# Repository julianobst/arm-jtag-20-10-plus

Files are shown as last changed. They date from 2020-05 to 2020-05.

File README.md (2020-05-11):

# arm-jtag-20-10-plus
KiCad project for ARM Cortex-M JTAG Adapter with 20, 10 and 6 pin target header

The adaptor can be used by a debug probe with a standard [ARM JTAG 20](http://infocenter.arm.com/help/index.jsp?topic=/com.arm.doc.dui0499d/BEHEIHCE.html) connector with 2.54 mm pitch and 2x10 pins. Like SEGGER J-Link, Olimex ARM-USB-TINY, STLINK-V3SET etc.

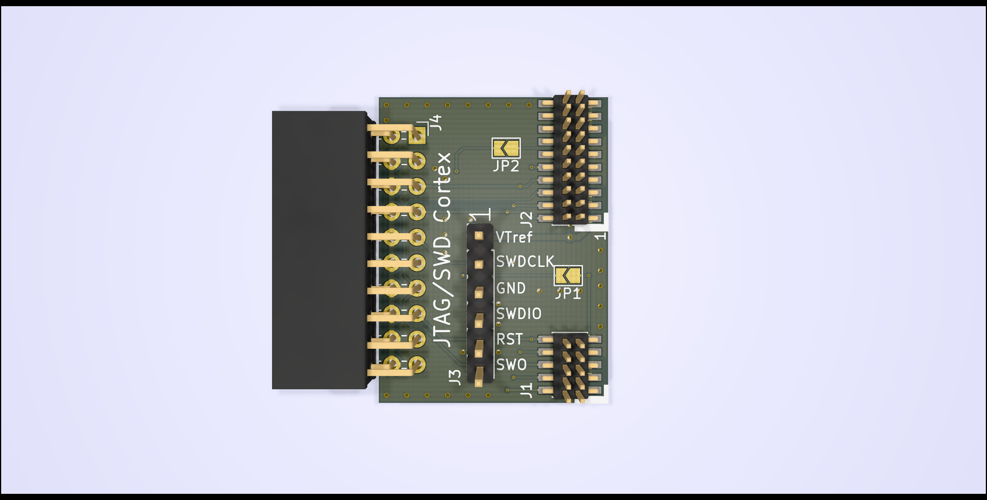
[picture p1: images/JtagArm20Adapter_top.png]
Adaptor top view

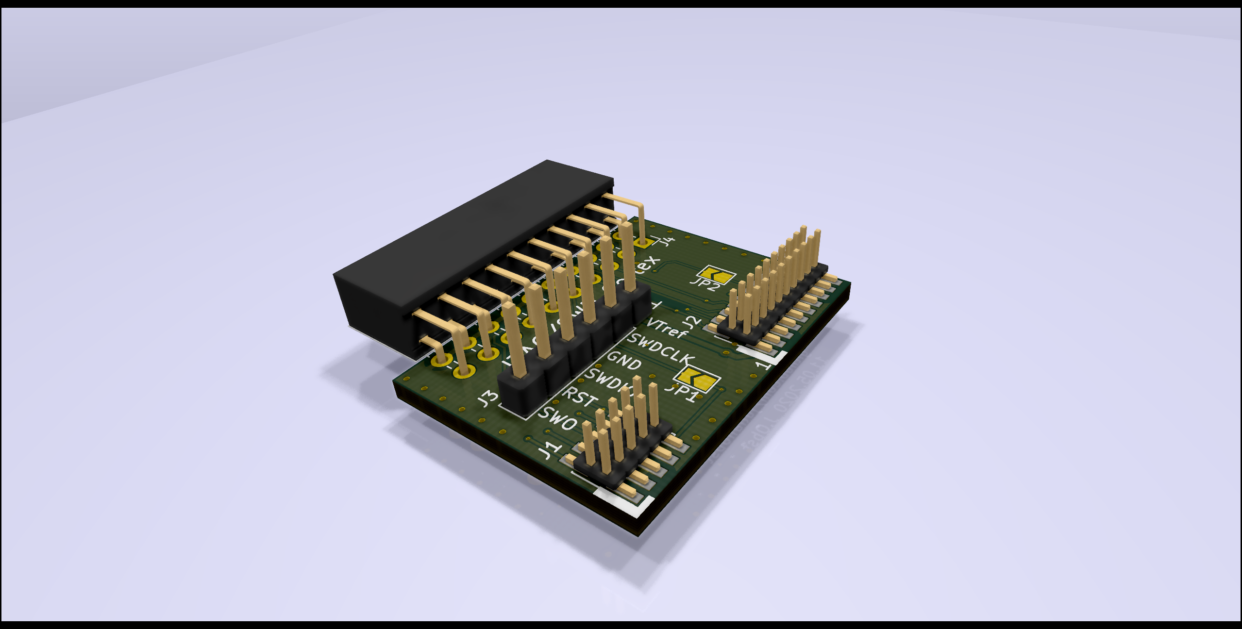
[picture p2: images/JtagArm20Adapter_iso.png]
Adaptor isometic view

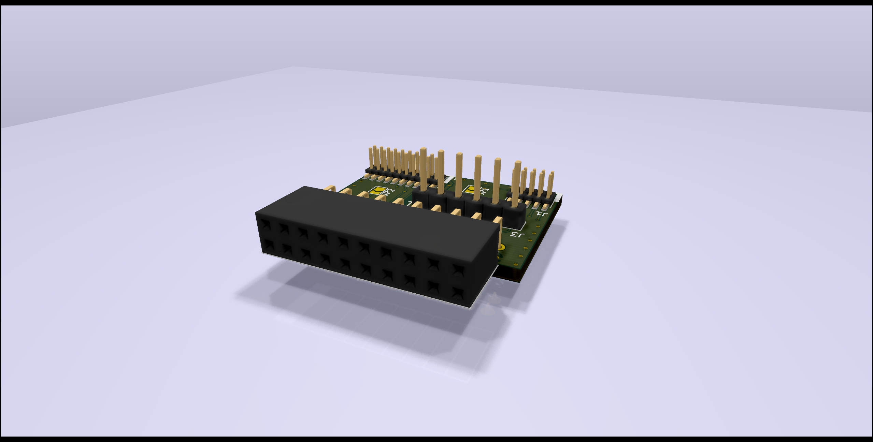
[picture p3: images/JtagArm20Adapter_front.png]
Adaptor front view


As target connectors, the adaptor provides a 20 and a 10 pin SWD Cortex debug connector with 1.27 mm pitch (J1, J2) and a simple 6 pin 2.54 mm pitch header for SWD (J3) according to the SWD header of the STM32 Nucleo board.

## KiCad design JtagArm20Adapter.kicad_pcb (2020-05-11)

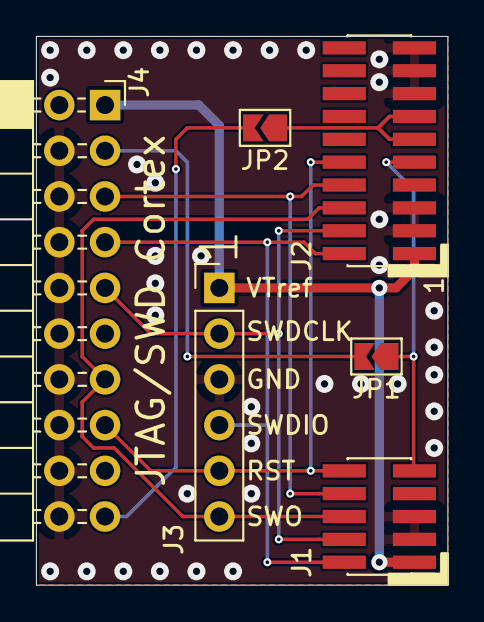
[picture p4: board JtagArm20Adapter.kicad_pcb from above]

Board: 2 copper layers, 22.9 x 30.5 mm, 6 parts (0 on the bottom side), 11 nets.

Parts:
J1: Conn_02x05_Odd_Even; PinHeader_2x05_P1.27mm_Vertical_SMD
J2: Conn_02x10_Odd_Even; PinHeader_2x10_P1.27mm_Vertical_SMD
J3: Conn_01x06; PinHeader_1x06_P2.54mm_Vertical
J4: Conn_02x10_Odd_Even; PinSocket_2x10_P2.54mm_Horizontal
JP1, JP2: SolderJumper_2_Open; SolderJumper-2_P1.3mm_Open_TrianglePad1.0x1.5mm

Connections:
/DBGACK: J4.19, JP2.2
/RESET: J1.10, J2.10, J3.5, J4.15
/SWDCLK\TCK: J1.4, J2.4, J3.2, J4.9
/SWDIO\TMS: J1.2, J2.2, J3.4, J4.7
/SWO\TDO: J1.6, J2.6, J3.6, J4.13
/TDI: J1.8, J2.8, J4.5
/VTref: J1.1, J2.1, J3.1, J4.1
/nTRST: J4.3, JP1.2
GND: J1.3, J1.5, J2.3, J2.5, J2.15, J2.17, J2.19, J3.3, J4.4, J4.6, J4.8, J4.10, J4.12, J4.14, J4.16, J4.18, J4.20
unnamed: J1.9, J2.9, JP1.1
unnamed: J2.11, J2.13, JP2.1

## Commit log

2020-04-26 First version used for prototype production
    [JtagArm20Adapter-B_Cu.gbr, JtagArm20Adapter-B_Mask.gbr, JtagArm20Adapter-B_SilkS.gbr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]
2020-04-26 Update README.md and add images of 3D rendered PCBA
2020-05-11 Change J2 from legacy IDC JTAG to Cortex debug pinout
    [JtagArm20Adapter-B_Cu.gbr, JtagArm20Adapter-B_Mask.gbr, JtagArm20Adapter-B_SilkS.gbr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]
